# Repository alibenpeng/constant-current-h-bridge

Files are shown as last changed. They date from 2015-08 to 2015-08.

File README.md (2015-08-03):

This is my first attempt at building a reverse pulse constant current source for
high aspect ratio through hole plating.

The idea is simple: 

It's just two constant current sources controlled by an ATMega328 combined with
an H-Bridge to reverse the current flow direction. Also, it includes a
PWM-output for a servo or BLDC speed controller and a switch-output for an
airpump.

This design is based on parts from my junk bin, so it uses BJTs where other
people would have used FETs. Feel free to modify the design to fit your needs.

License: The latest GPL

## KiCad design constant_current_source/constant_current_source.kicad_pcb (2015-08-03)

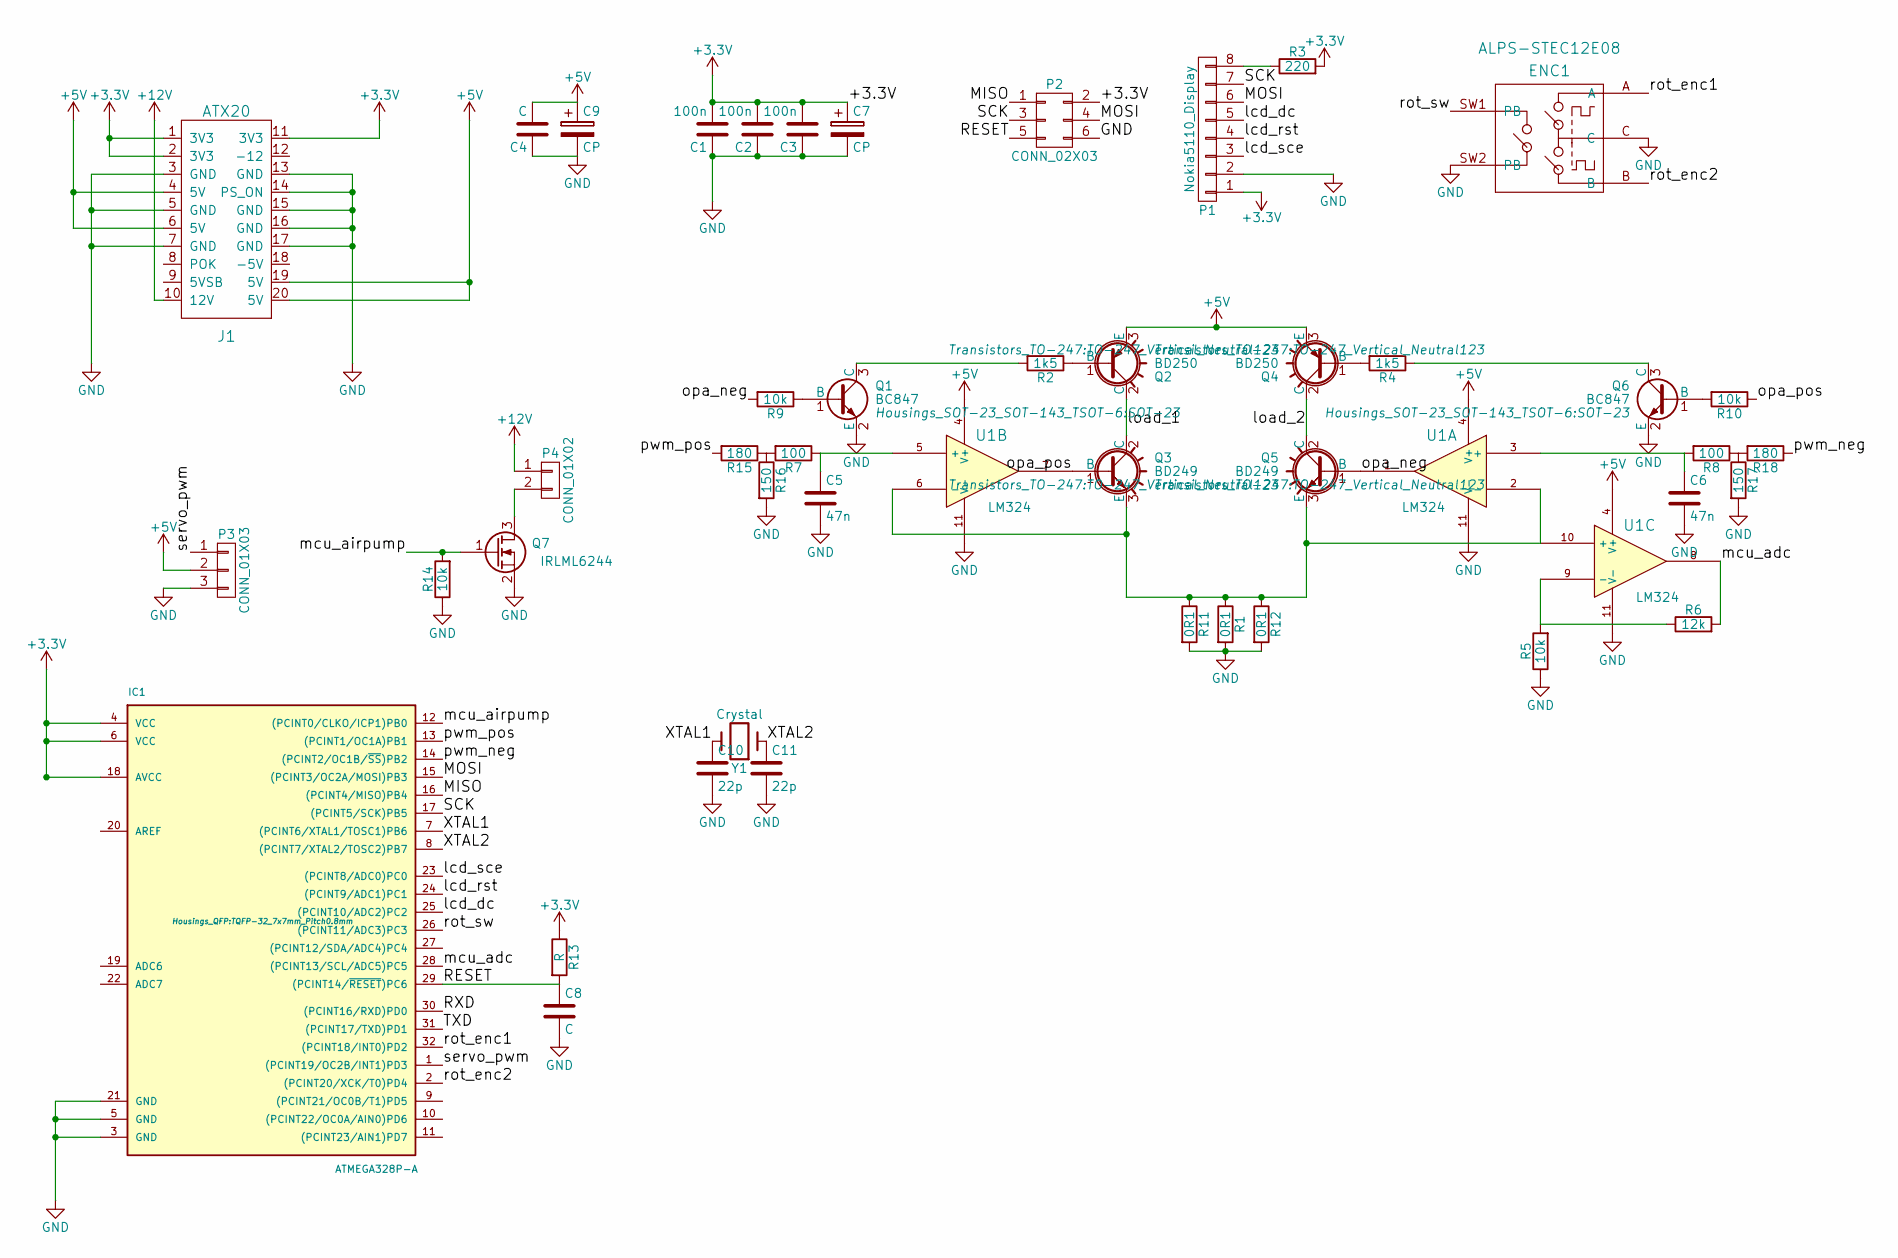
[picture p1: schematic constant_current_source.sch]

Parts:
C1, C2, C3: 100n; C_0603
C4: C; C_0805
C5, C6: 47n; C_0603
C7, C9: CP; Elko_vert_20x10mm_RM5
C8: C; C_0603
C10, C11: 22p; C_0603
ENC1: ALPS-STEC12E08
IC1: ATMEGA328P-A; TQFP-32_7x7mm_Pitch0.8mm
J1: ATX20; Molex_minifit_jr_5566_39-29-9203_20pin
P1: Nokia5110_Display
P2: CONN_02X03; Pin_Header_Straight_2x03
P3: CONN_01X03; Pin_Header_Straight_1x03
P4: CONN_01X02; Pin_Header_Straight_1x02
Q1, Q6: BC847; SOT-23
Q2, Q4: BD250; TO-247_Vertical_Neutral123
Q3, Q5: BD249; TO-247_Vertical_Neutral123
Q7: IRLML6244; SOT-23
R1, R11, R12: 0R1; Resistor_Ceramic_Horizontal_L23mm-W9mm-H9mm-p30mm
R2, R4: 1k5; R_0603
R3: 220; R_0603
R5, R9, R10, R14: 10k; R_0603
R6: 12k; R_0603
R7, R8: 100; R_0603
R13: R; R_0603
R15, R18: 180; R_0603
R16, R17: 150; R_0603
U1: LM324; SOIC-14_N
Y1: Crystal; Crystal_HC48-U_Vertical

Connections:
+3V3: C1.2, C2.2, C3.2, C7.1, IC1.4 (VCC), IC1.6 (VCC), IC1.18 (AVCC), J1.1 (3V3), J1.2 (3V3), J1.11 (3V3), P1.1 (VCC), P2.2, R3.2, R13.1
+5V: C4.2, C9.1, J1.4 (5V), J1.6 (5V), J1.19 (5V), J1.20 (5V), P3.2, Q2.3 (E), Q4.3 (E), U1.4 (V+)
+12V: J1.10 (12V), P4.1
/MISO: IC1.16 ((PCINT4/MISO)PB4), P2.1
/MOSI: IC1.15 ((PCINT3/OC2A/MOSI)PB3), P1.6 (DN(MOSI)), P2.4
/RESET: C8.1, IC1.29 ((PCINT14/~RESET~)PC6), P2.5, R13.2
/RXD: IC1.30 ((PCINT16/RXD)PD0)
/SCK: IC1.17 ((PCINT5/SCK)PB5), P1.7 (SCLK), P2.3
/TXD: IC1.31 ((PCINT17/TXD)PD1)
/XTAL1: C10.1, IC1.7 ((PCINT6/XTAL1/TOSC1)PB6), Y1.2
/XTAL2: C11.1, IC1.8 ((PCINT7/XTAL2/TOSC2)PB7), Y1.1
/lcd_dc: IC1.25 ((PCINT10/ADC2)PC2), P1.5 (D/C)
/lcd_rst: IC1.24 ((PCINT9/ADC1)PC1), P1.4 (RST)
/lcd_sce: IC1.23 ((PCINT8/ADC0)PC0), P1.3 (SCE)
/load_1: Q2.2 (C), Q3.2 (C)
/load_2: Q4.2 (C), Q5.2 (C)
/mcu_adc: IC1.28 ((PCINT13/SCL/ADC5)PC5), R6.2, U1.8
/mcu_airpump: IC1.12 ((PCINT0/CLKO/ICP1)PB0), Q7.1 (G), R14.2
/opa_neg: Q5.1 (B), R9.2, U1.1
/opa_pos: Q3.1 (B), R10.1, U1.7
/pwm_neg: IC1.14 ((PCINT2/OC1B/~SS~)PB2), R18.1
/pwm_pos: IC1.13 ((PCINT1/OC1A)PB1), R15.2
/rot_enc1: ENC1.A, IC1.32 ((PCINT18/INT0)PD2)
/rot_enc2: ENC1.B, IC1.2 ((PCINT20/XCK/T0)PD4)
/rot_sw: ENC1.SW1 (PB), IC1.26 ((PCINT11/ADC3)PC3)
/servo_pwm: IC1.1 ((PCINT19/OC2B/INT1)PD3), P3.1
unnamed: C5.1, R7.1, U1.5 (+)
unnamed: C6.1, R8.2, U1.3 (+)
unnamed: P1.8 (LED), R3.1
unnamed: P4.2, Q7.3 (D)
unnamed: Q1.1 (B), R9.1
unnamed: Q1.3 (C), R2.2
unnamed: Q2.1 (B), R2.1
unnamed: Q4.1 (B), R4.2
unnamed: Q6.1 (B), R10.2
unnamed: Q6.3 (C), R4.1
unnamed: R5.2, R6.1, U1.9 (-)
unnamed: R7.2, R15.1, R16.1
unnamed: R8.1, R17.1, R18.2

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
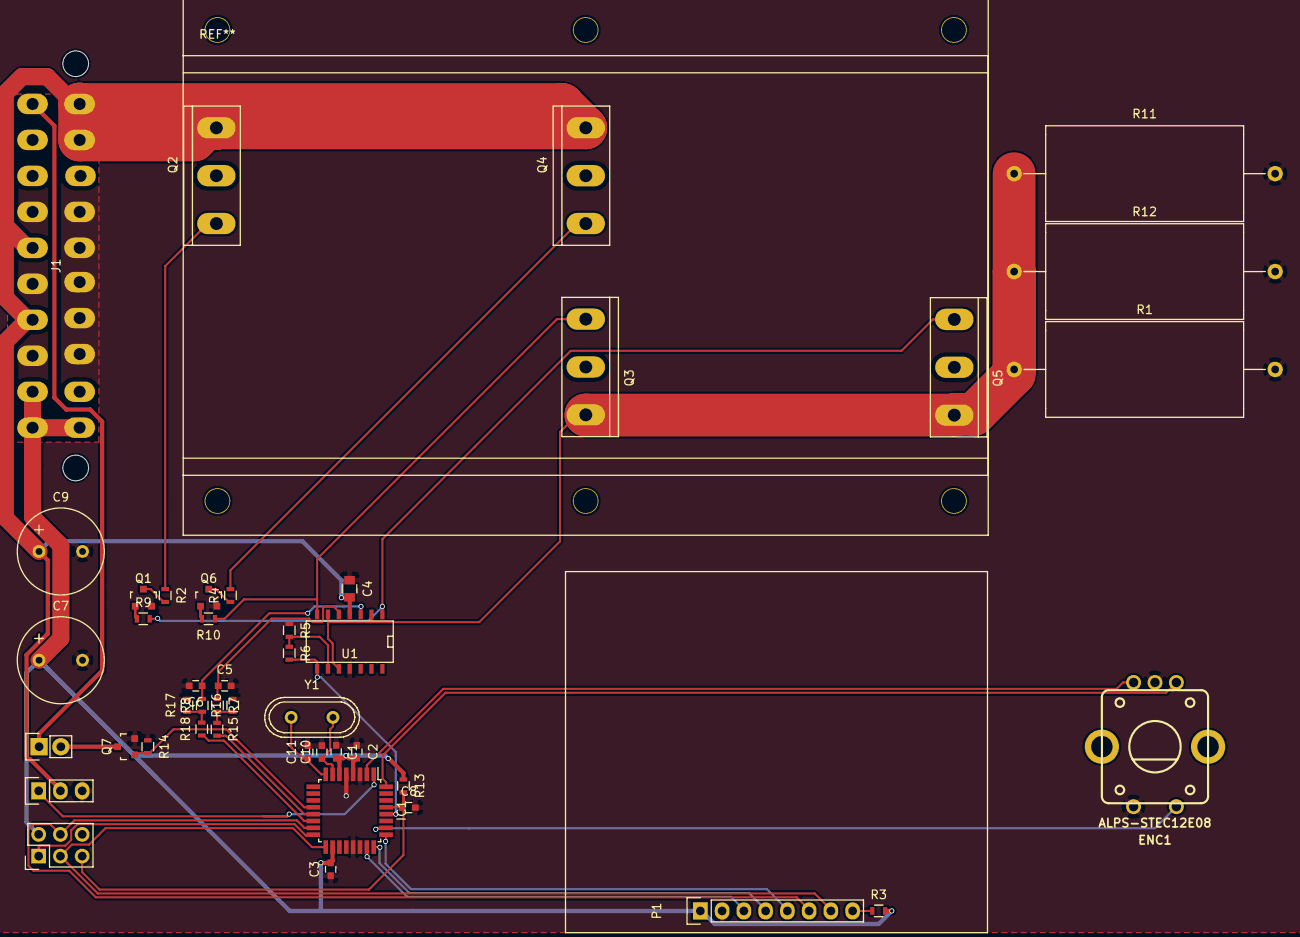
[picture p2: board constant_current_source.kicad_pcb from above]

Board: 2 copper layers, 45 parts (0 on the bottom side), 39 nets.
